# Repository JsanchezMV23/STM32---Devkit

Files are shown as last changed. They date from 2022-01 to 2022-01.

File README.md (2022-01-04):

# STM32 - Devkit with USB Connection + RGB Led

**STM32 based breakboard/devkit with USB connection and RGB Led with multiple pinout for ESP32 prototyping/code testing from scratch.** This small board has multiple connection for almost all GPIOs on the STM32F1 with a RGB led for simple code testing, a jumper for Booting and USB power/data connection.

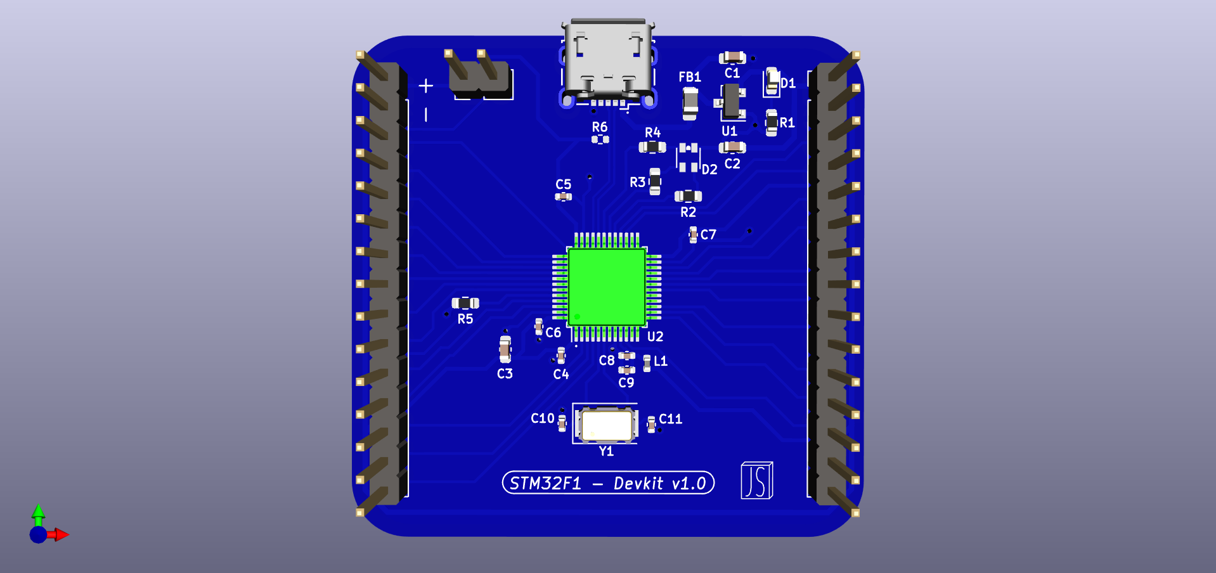
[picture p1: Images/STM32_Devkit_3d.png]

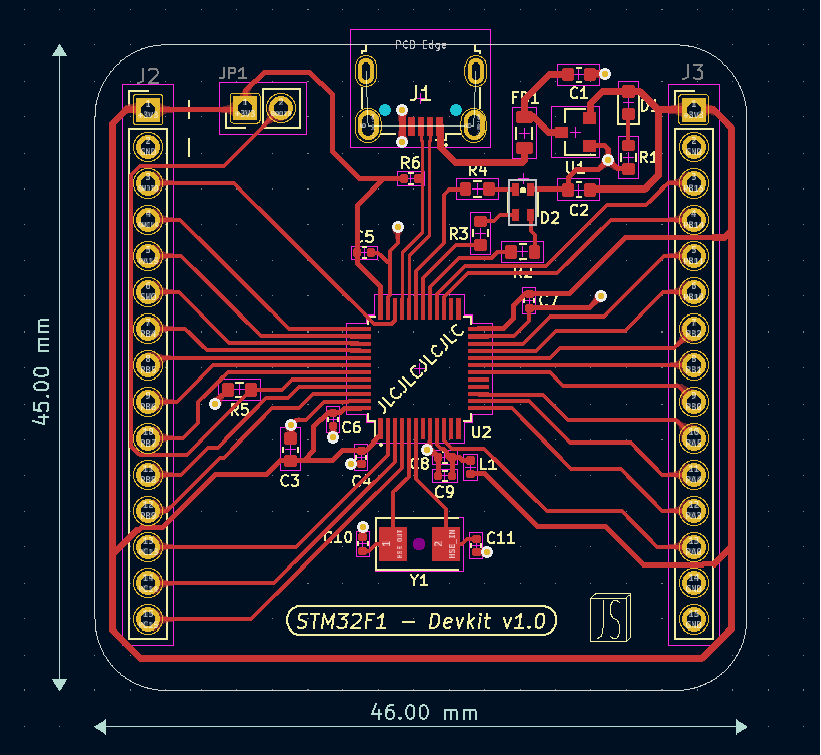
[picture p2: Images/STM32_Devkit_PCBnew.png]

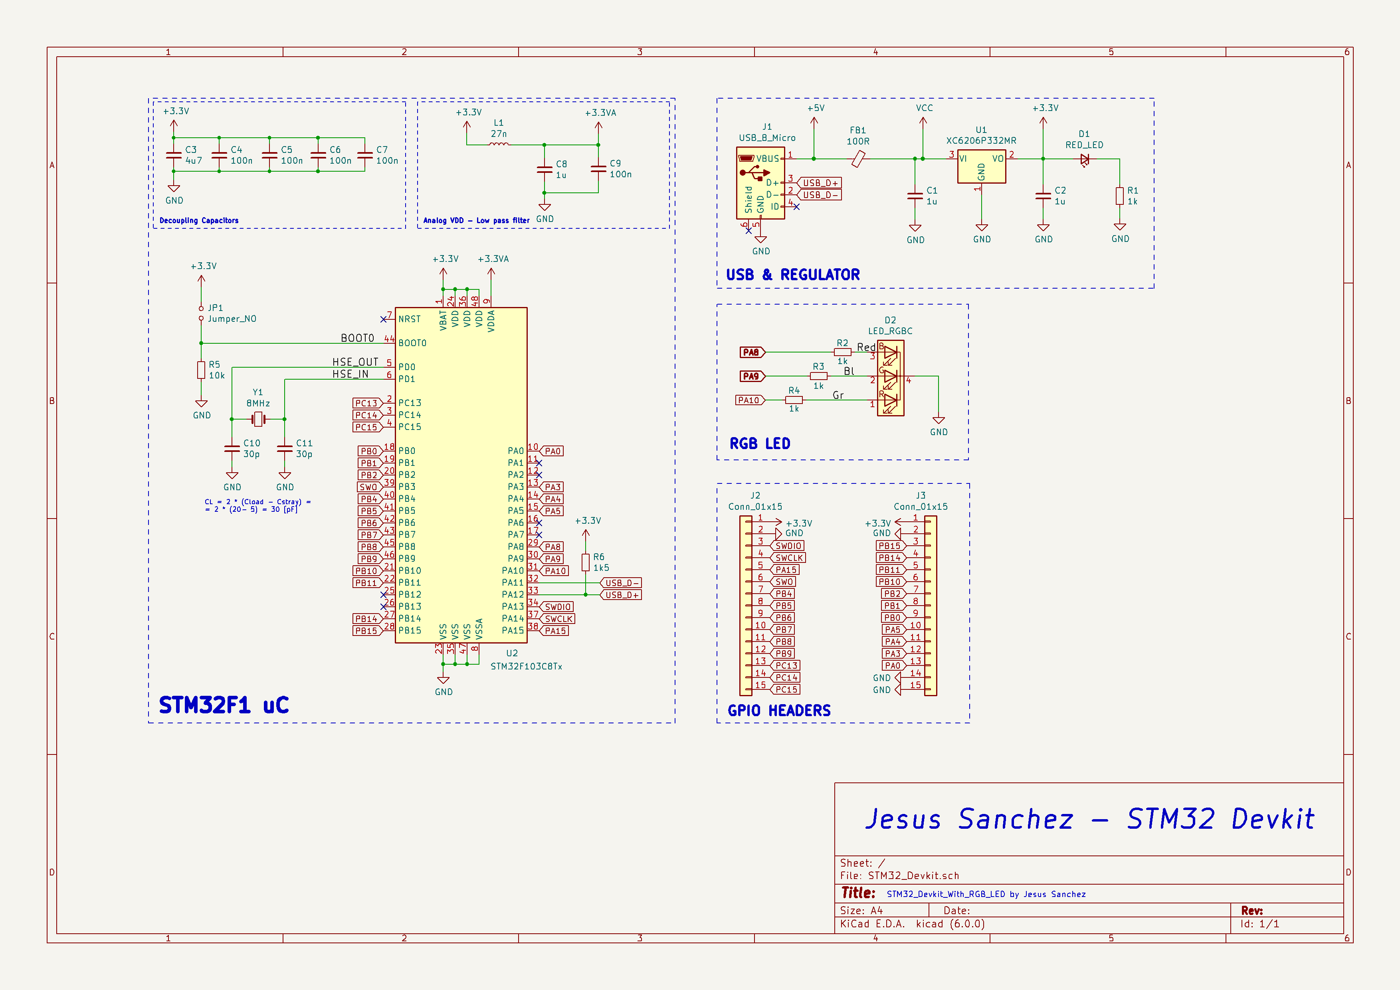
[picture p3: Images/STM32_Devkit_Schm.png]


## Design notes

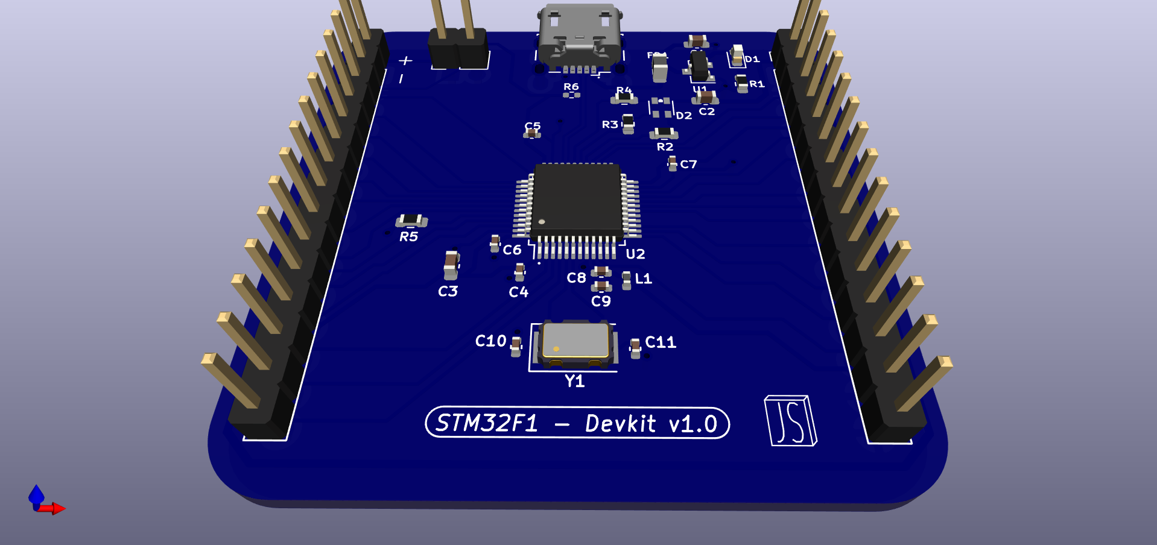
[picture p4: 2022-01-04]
Images/STM32_Devkit_3d_2.png

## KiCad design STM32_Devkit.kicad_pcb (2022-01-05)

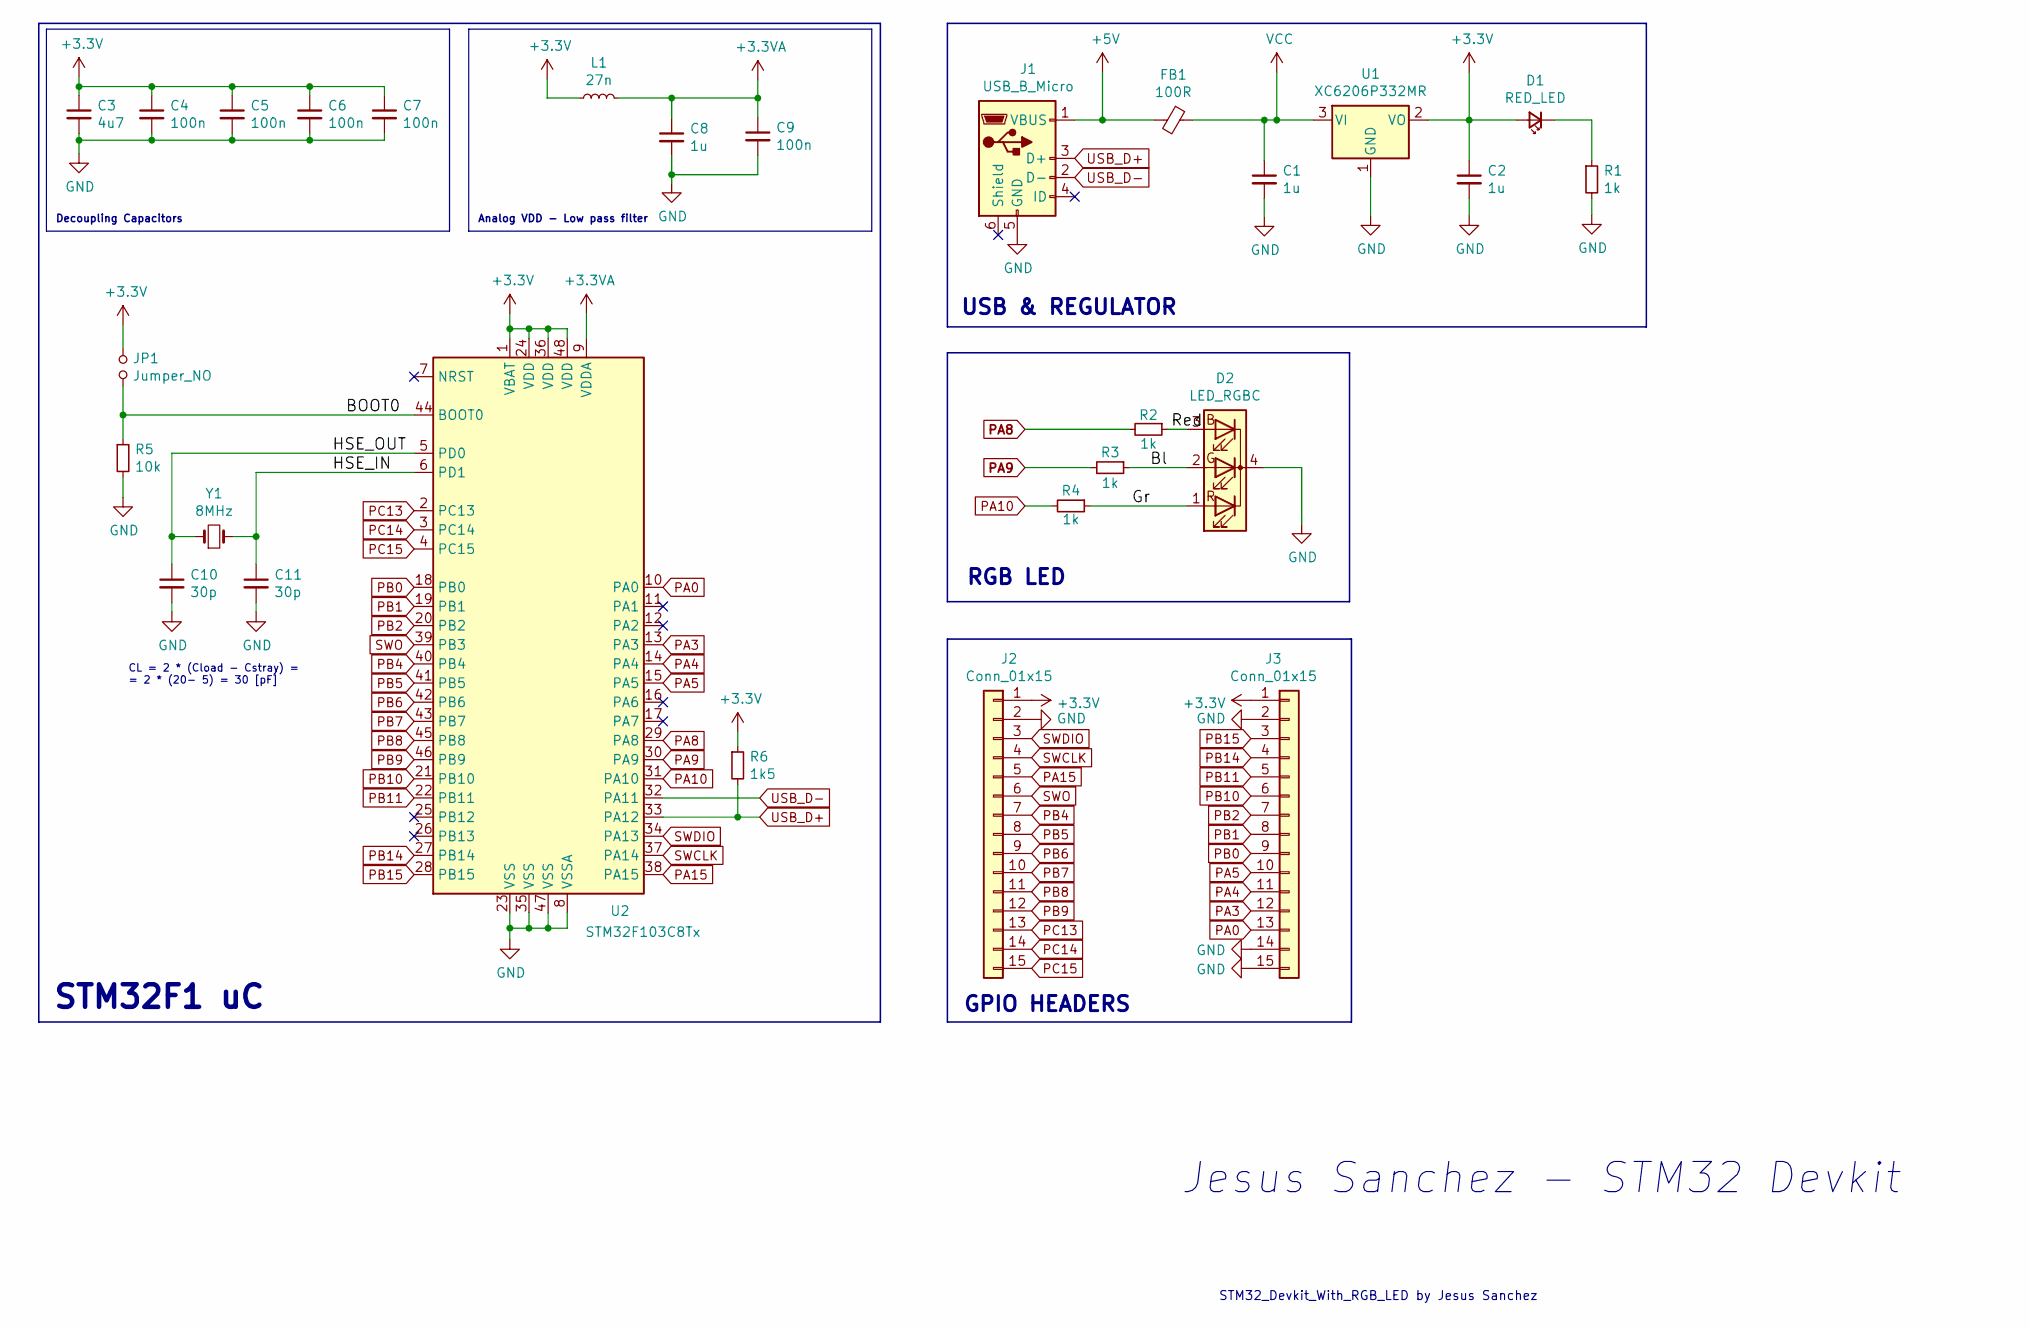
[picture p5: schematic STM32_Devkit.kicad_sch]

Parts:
C1, C2: 1u; C_0603_1608Metric
C3: 4u7; C_0603_1608Metric
C4, C5, C6, C7, C9: 100n; C_0402_1005Metric
C8: 1u; C_0402_1005Metric
C10, C11: 30p; C_0402_1005Metric
D1: RED_LED; LED_0603_1608Metric
D2: LED_RGBC; RGB_LED_2.1x2.1mm
FB1: 100R; L_0805_2012Metric
J1: USB_B_Micro; USB_Micro-B_Wuerth_629105150521
J2, J3: Conn_01x15; PinHeader_1x15_P2.54mm_Vertical
JP1: Jumper_NO; PinHeader_1x02_P2.54mm_Vertical
L1: 27n; L_0402_1005Metric
R1, R2, R3, R4: 1k; R_0603_1608Metric
R5: 10k; R_0603_1608Metric
R6: 1k5; R_0402_1005Metric
U1: XC6206P332MR; SOT-23
U2: STM32F103C8Tx; LQFP-48_7x7mm_P0.5mm
Y1: 8MHz; Crystal_SMD_5032-2Pin_5.0x3.2mm

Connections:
+3.3VA: C8.1, C9.1, L1.2, U2.9 (VDDA)
+3V3: C2.1, C3.1, C4.1, C5.1, C6.1, C7.1, D1.2 (A), J2.1, J3.1, JP1.1, L1.1, R6.1, U1.2 (VO), U2.1 (VBAT), U2.24 (VDD), U2.36 (VDD), U2.48 (VDD)
+5V: FB1.2, J1.1 (VBUS)
/BOOT0: JP1.2, R5.1, U2.44 (BOOT0)
/Bl: D2.2 (GA), R3.1
/Gr: D2.1 (RA), R4.1
/HSE_IN: C11.1, U2.6 (PD1), Y1.2
/HSE_OUT: C10.1, U2.5 (PD0), Y1.1
/Red: D2.3 (BA), R2.1
GND: C1.2, C2.2, C3.2, C4.2, C5.2, C6.2, C7.2, C8.2, C9.2, C10.2, C11.2, D2.4 (K), J1.5 (GND), J2.2, J3.2, J3.14, J3.15, R1.2, R5.2, U1.1 (GND), U2.8 (VSSA), U2.23 (VSS), U2.35 (VSS), U2.47 (VSS)
unnamed: D1.1 (K), R1.1
PA0: J3.13, U2.10 (PA0)
PA3: J3.12, U2.13 (PA3)
PA4: J3.11, U2.14 (PA4)
PA5: J3.10, U2.15 (PA5)
PA8: R2.2, U2.29 (PA8)
PA9: R3.2, U2.30 (PA9)
PA10: R4.2, U2.31 (PA10)
PA15: J2.5, U2.38 (PA15)
PB0: J3.9, U2.18 (PB0)
PB1: J3.8, U2.19 (PB1)
PB2: J3.7, U2.20 (PB2)
PB4: J2.7, U2.40 (PB4)
PB5: J2.8, U2.41 (PB5)
PB6: J2.9, U2.42 (PB6)
PB7: J2.10, U2.43 (PB7)
PB8: J2.11, U2.45 (PB8)
PB9: J2.12, U2.46 (PB9)
PB10: J3.6, U2.21 (PB10)
PB11: J3.5, U2.22 (PB11)
PB14: J3.4, U2.27 (PB14)
PB15: J3.3, U2.28 (PB15)
PC13: J2.13, U2.2 (PC13)
PC14: J2.14, U2.3 (PC14)
PC15: J2.15, U2.4 (PC15)
SWCLK: J2.4, U2.37 (PA14)
SWDIO: J2.3, U2.34 (PA13)
SWO: J2.6, U2.39 (PB3)
USB_D+: J1.3 (D+), R6.2, U2.33 (PA12)
USB_D-: J1.2 (D-), U2.32 (PA11)
VCC: C1.1, FB1.1, U1.3 (VI)

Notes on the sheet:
Decoupling Capacitors
CL = 2 * (Cload - Cstray) = = 2 * (20- 5) = 30 [pF]
GPIO HEADERS
STM32_Devkit_With_RGB_LED by Jesus Sanchez
USB & REGULATOR
RGB LED
Jesus Sanchez - STM32 Devkit
Analog VDD - Low pass filter
STM32F1 uC

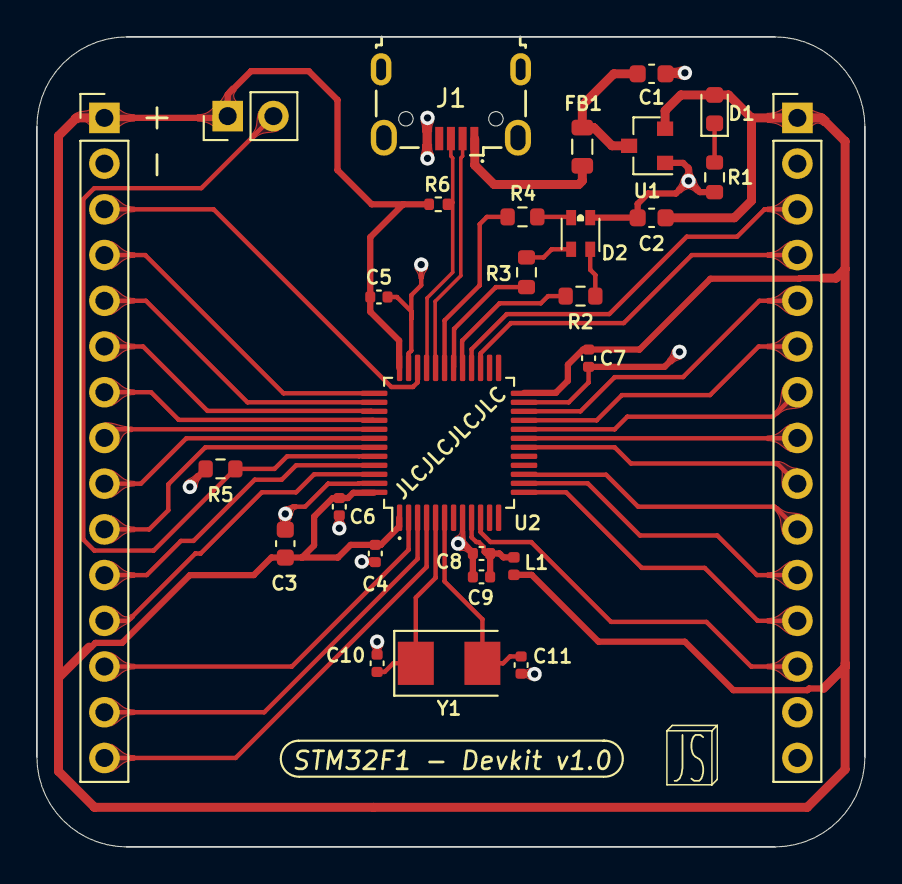
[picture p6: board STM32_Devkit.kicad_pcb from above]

Board: 2 copper layers, 46.0 x 45.0 mm, 28 parts (0 on the bottom side), 41 nets.
